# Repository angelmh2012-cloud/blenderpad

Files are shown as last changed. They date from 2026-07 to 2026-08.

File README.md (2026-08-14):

# BlenderPad

BlenderPad is a custom macropad project built for Blender workflow shortcuts, gaming controls, and a small OLED mini game. It is designed to be programmable with CircuitPython and KMK firmware, making it easy to customize for different use cases.



## Project Overview
This project started as a beginner-friendly hardware and firmware build for HackClub. The goal is to create a compact keypad that can:
- trigger Blender shortcuts quickly
- switch between different key modes
- show the active mode on an OLED display
- support simple gaming-style input mappings

## What is included
This repository contains:
- a beginner-friendly 3D-printable case concept
- PCB design files
- firmware for the microcontroller
- a custom main script for mode switching and OLED output

## Hardware Features
The current design uses:
- an encoder for changing modes
- an OLED display for showing the active mode
- keys connected to GPIO pins for custom actions
- support for multiple functional profiles
  



## Firmware Details
The firmware is written in Python and uses KMK for keyboard behavior. The device supports:
- Blender shortcuts mode
- Friday Night Funkin mode
- a mini game mode displayed on the OLED screen

## Pin Layout
- SDA: D4
- SCL: D5
- Encoder: D1
- Keys: D7 to D10

## Software Requirements
The firmware relies on the following Python libraries:
- adafruit-circuitpython-ssd1306
- adafruit-circuitpython-busdevice
- adafruit-circuitpython-framebuf

## How to Use It
1. Flash CircuitPython onto the microcontroller.
2. Copy the firmware files and required libraries to the device.
3. Upload the main script.
4. Power the board and test the keys and encoder.

## Notes
This is a beginner project, so the design and firmware are still evolving. The main goal is to learn hardware programming, PCB design, and embedded firmware development in a fun and practical way.

## Future Ideas
Possible improvements include:
- adding more Blender shortcuts
- creating custom profiles for different programs
- improving the OLED mini game
- refining the case design for a cleaner final build

## Summary
BlenderPad is a fun, hands-on project that combines electronics, firmware, and creativity into one compact macropad. It is a great example of how small embedded projects can become useful tools for everyday tasks.

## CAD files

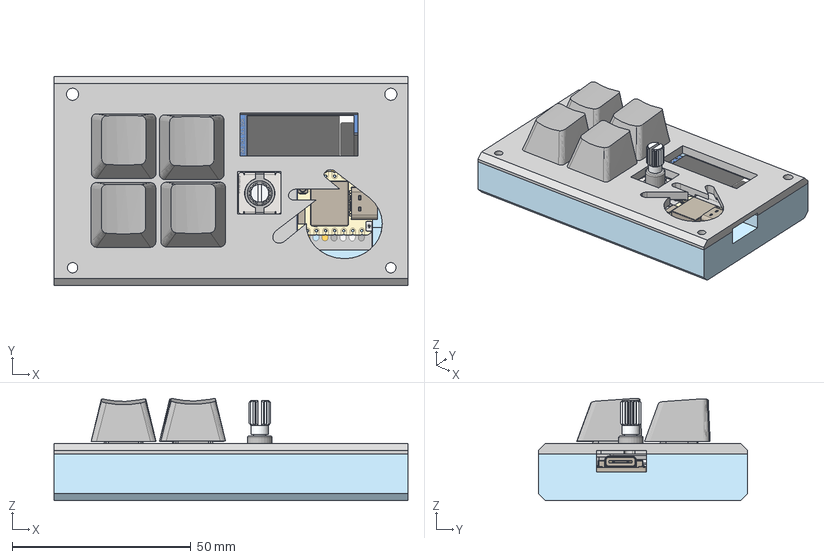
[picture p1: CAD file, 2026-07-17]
CAD/BlenderPad v1.step
99.0 x 58.5 x 28.6 mm
Surface 43
Surface 364
Surface 344
Surface 180
Surface 40
Surface 131
Surface 284
Surface 30
Surface 79
Surface 341
Surface 146
Surface 207
Surface 29
Surface 252
Surface 245
Surface 107
Surface 33
Surface 233
Surface 373
Surface 37
Surface 99
Surface 230
Surface 282
Surface 194
Surface 178
Surface 261
Surface 383
Surface 309
Surface 257
Surface 155
Surface 397
Surface 321
Surface 44
Surface 185
Surface 162
Surface 269
Surface 313
Surface 141
Surface 57
Surface 154
Surface 12
Surface 324
Surface 115
Surface 147
Surface 291
Surface 231
Surface 243
Surface 256
Surface 320
Surface 312
Surface 145
Surface 116
Surface 235
Surface 381
Seeed Studio XIAO-ESP32-C6
Surface 21
Surface 6
Surface 259
Surface 159
Surface 77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

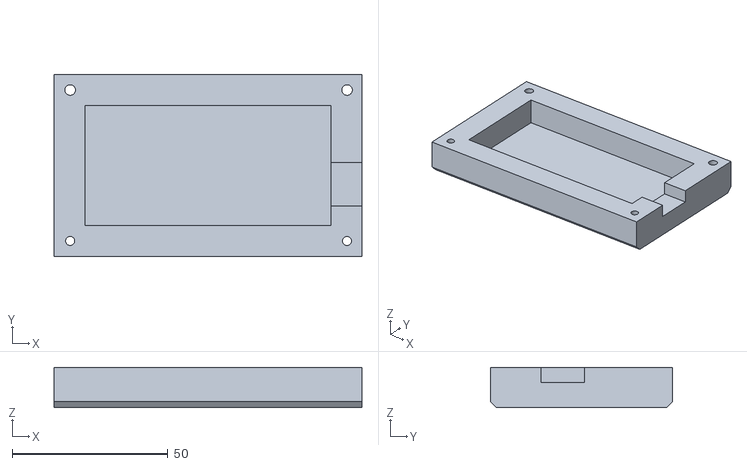
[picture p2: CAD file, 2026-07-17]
Production/Bottom(1).stl
99.0 x 58.5 x 13.0

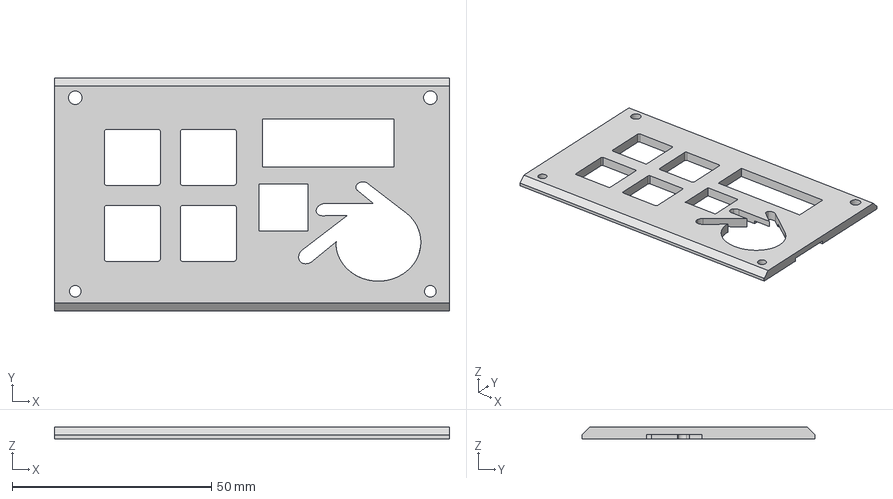
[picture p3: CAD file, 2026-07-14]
CAD/Top.step
99.0 x 58.5 x 3.00 mm

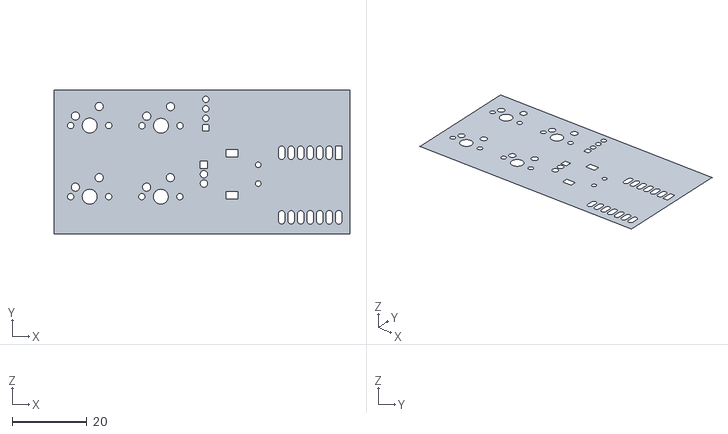
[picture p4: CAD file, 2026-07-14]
CAD/PCB surface.stl
79.0 x 38.5 x 0

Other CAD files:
Production/Top(1).stl
CAD/Bottom.step

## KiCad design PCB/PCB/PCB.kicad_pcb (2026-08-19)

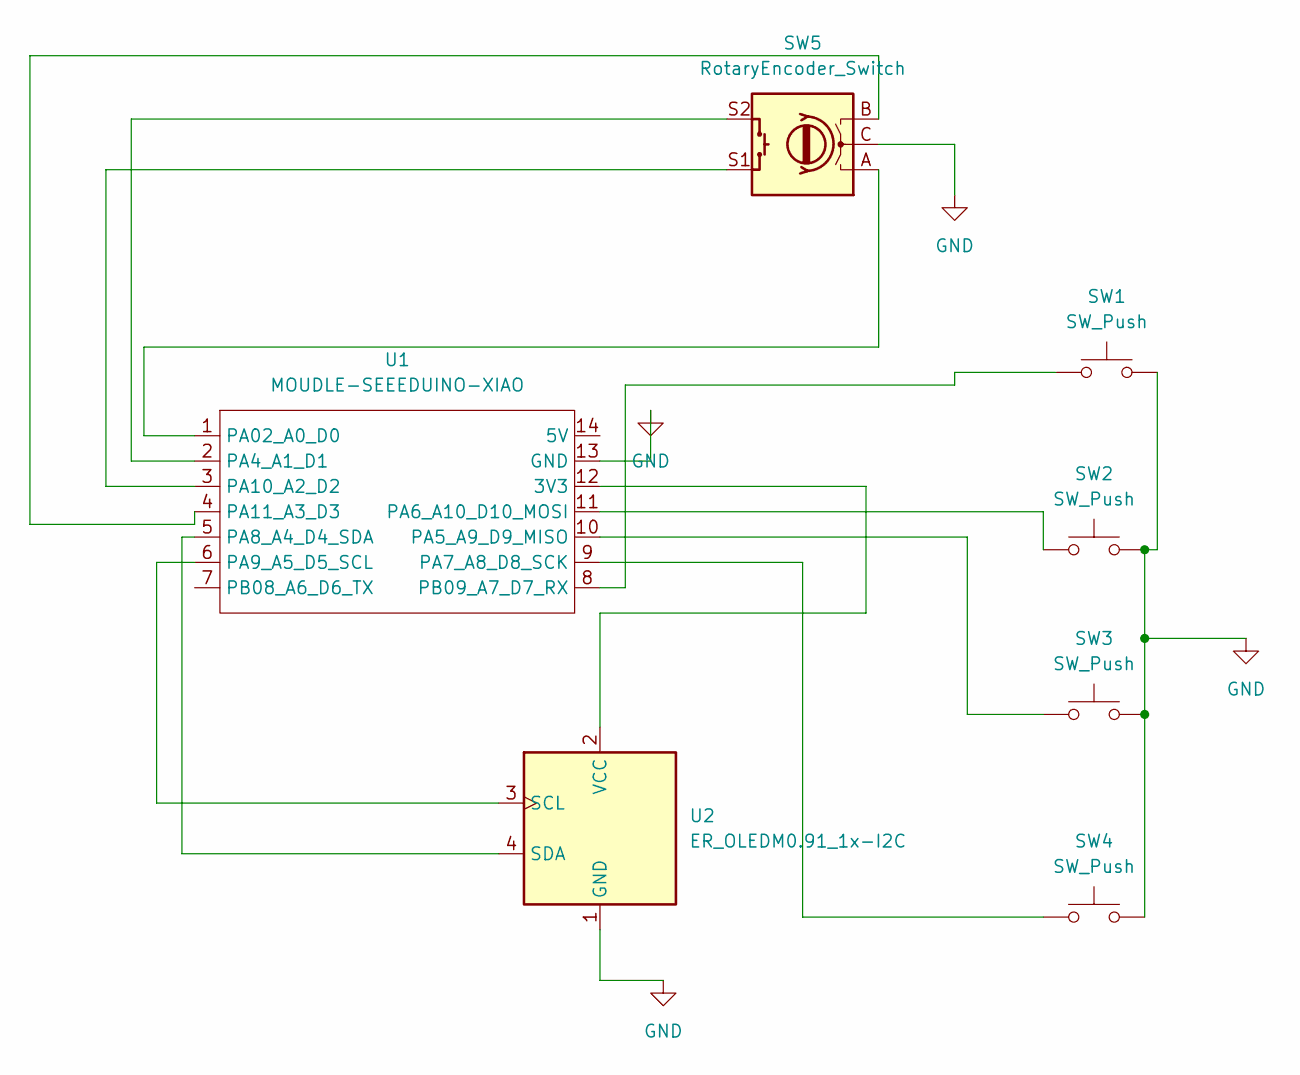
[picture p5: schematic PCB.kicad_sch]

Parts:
SW1, SW2, SW3, SW4: SW_Push; SW_Cherry_MX_1.00u_PCB
SW5: RotaryEncoder_Switch; RotaryEncoder_Alps_EC11E-Switch_Vertical_H20mm
U1: MOUDLE-SEEEDUINO-XIAO; XIAO-Generic-Hybrid-14P-2.54-21X17.8MM
U2: ER_OLEDM0.91_1x-I2C

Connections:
GND: SW1.2, SW2.2, SW3.2, SW4.2, SW5.C, U1.13 (GND), U2.1 (GND)
unnamed: U1.12 (3V3), U2.2 (VCC)
unnamed: SW5.A, U1.1 (PA02_A0_D0)
unnamed: SW5.S2, U1.2 (PA4_A1_D1)
unnamed: SW3.1, U1.10 (PA5_A9_D9_MISO)
unnamed: SW2.1, U1.11 (PA6_A10_D10_MOSI)
unnamed: SW4.1, U1.9 (PA7_A8_D8_SCK)
unnamed: U1.5 (PA8_A4_D4_SDA), U2.4 (SDA)
unnamed: U1.6 (PA9_A5_D5_SCL), U2.3 (SCL)
unnamed: SW5.S1, U1.3 (PA10_A2_D2)
unnamed: SW5.B, U1.4 (PA11_A3_D3)
unnamed: SW1.1, U1.8 (PB09_A7_D7_RX)

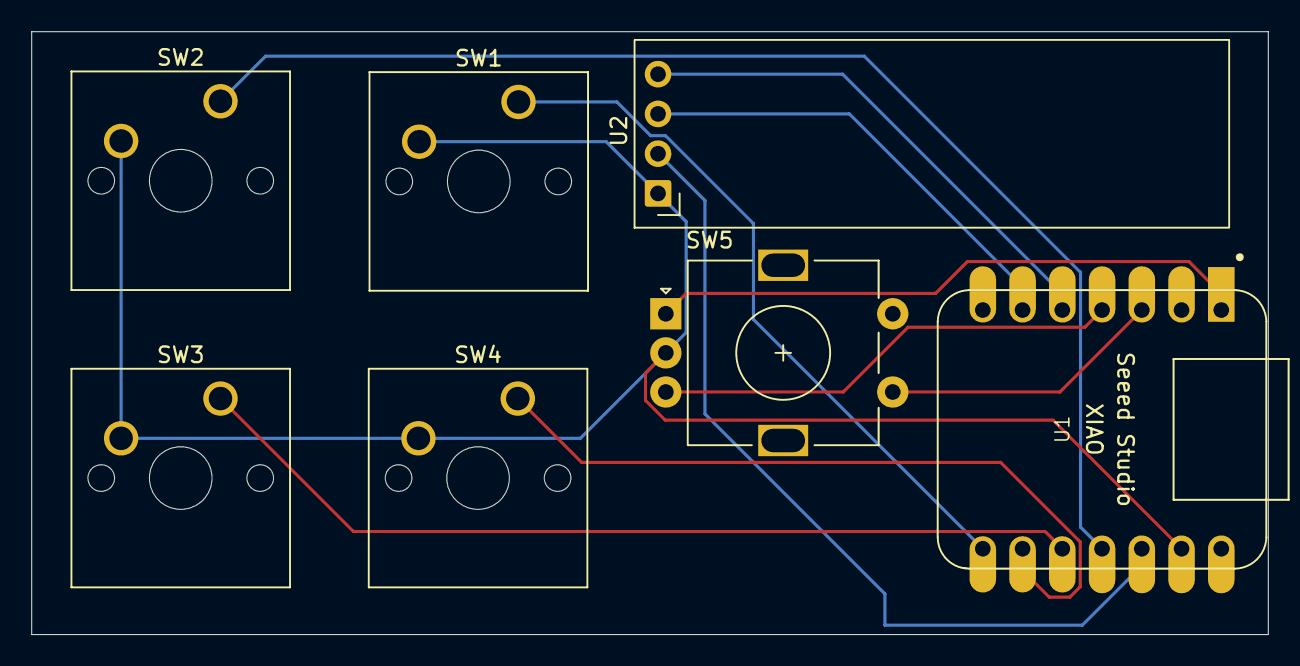
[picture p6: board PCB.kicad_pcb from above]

Board: 2 copper layers, 79.0 x 38.5 mm, 7 parts (0 on the bottom side), 12 nets.

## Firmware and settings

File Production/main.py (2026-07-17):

import time

import board
from kmk.kmk_keyboard import KMKKeyboard
from kmk.keys import KC
from kmk.modules.holdtap import HoldTap
from kmk.modules.macros import Macro

try:
    import digitalio
except ImportError:  # pragma: no cover - handles host-side syntax checks
    digitalio = None

try:
    import adafruit_ssd1306
except ImportError:  # pragma: no cover - handles host-side syntax checks
    adafruit_ssd1306 = None

from kmk.scanners.diode import DiodeOrientation

modtap = HoldTap()
macros = Macro()
keyboard = KMKKeyboard()

keyboard.modules.append(modtap)
keyboard.modules.append(macros)

# --- Key layout: 2x2 matrix mapped to D7-D10 ---
keyboard.col_pins = ()
keyboard.row_pins = ()
keyboard.diode_orientation = DiodeOrientation.COL2ROW

ENFOCAR_OBJ = KC.F
DUPLICAR_OBJ = KC.H
MOSTRAR_TODO = KC.LALT(KC.H)
ABRIR_PROP = KC.N

MODES = ["Blender Shortcuts", "Friday Night Funkin", "Mini Game"]
MODE_HINTS = [
    "F=focus | H=hide | Alt+H=show all",
    "Arrows for notes | A/S/W/D as extras",
    "OLED mini game + button actions",
]
MODE_ACTIONS = [
    [ENFOCAR_OBJ, DUPLICAR_OBJ, MOSTRAR_TODO, ABRIR_PROP],
    [KC.LEFT, KC.DOWN, KC.UP, KC.RIGHT],
    [KC.A, KC.S, KC.W, KC.D],
]

current_mode = 0


def get_pin(*names):
    for name in names:
        pin = getattr(board, name, None)
        if pin is not None:
            return pin
    raise RuntimeError("Could not find a matching pin for the requested hardware")


# --- Hardware pins ---
SDA_PIN = get_pin("GP4", "D4")
SCL_PIN = get_pin("GP5", "D5")
ENCODER_PIN = get_pin("GP1", "D1")
BUTTON_PINS = [get_pin("GP7", "D7"), get_pin("GP8", "D8"), get_pin("GP9", "D9"), get_pin("GP10", "D10")]


# --- OLED setup ---
if digitalio is not None and adafruit_ssd1306 is not None:
    import busio

    i2c = busio.I2C(SCL_PIN, SDA_PIN)
    oled = adafruit_ssd1306.SSD1306_I2C(128, 32, i2c, addr=0x3C)
else:
    oled = None


# --- Button inputs ---
if digitalio is not None:
    buttons = []
    for pin in BUTTON_PINS:
        io = digitalio.DigitalInOut(pin)
        io.direction = digitalio.Direction.INPUT
        io.pull = digitalio.Pull.UP
        buttons.append(io)

    encoder_button = digitalio.DigitalInOut(ENCODER_PIN)
    encoder_button.direction = digitalio.Direction.INPUT
    encoder_button.pull = digitalio.Pull.UP
else:
    buttons = []
    encoder_button = None

button_last_states = [False] * len(buttons)
encoder_last_state = False


def draw_status():
    if oled is None:
        return

    oled.fill(0)
    oled.text("Mode:", 0, 0, 1)
    oled.text(MODES[current_mode][:12], 0, 10, 1)
    oled.text(MODE_HINTS[current_mode][:16], 0, 20, 1)
    oled.show()


# --- Simple OLED mini game ---
ball_x = 10
ball_y = 10
ball_dx = 2
ball_dy = 1


def draw_game_frame():
    global ball_x, ball_y, ball_dx, ball_dy

    if oled is None:
        return

    oled.fill(0)
    oled.text("Mini Game", 0, 0, 1)
    oled.pixel(ball_x, ball_y, 1)
    oled.pixel(ball_x + 1, ball_y, 1)
    oled.pixel(ball_x, ball_y + 1, 1)
    oled.pixel(ball_x + 1, ball_y + 1, 1)

    ball_x += ball_dx
    ball_y += ball_dy

    if ball_x <= 0 or ball_x >= 126:
        ball_dx *= -1
    if ball_y <= 8 or ball_y >= 30:
        ball_dy *= -1

    oled.show()


# --- Helper to send key presses ---
def send_key(action):
    try:
        keyboard.tap_key(action)
    except AttributeError:
        pass


# --- Background task for encoder/button handling and OLED output ---
def control_loop():
    global current_mode, button_last_states, encoder_last_state

    while True:
        if buttons:
            for idx, button in enumerate(buttons):
                pressed = not button.value
                if pressed and not button_last_states[idx]:
                    action = MODE_ACTIONS[current_mode][idx]
                    send_key(action)
                button_last_states[idx] = pressed

        if encoder_button is not None:
            pressed = not encoder_button.value
            if pressed and not encoder_last_state:
                current_mode = (current_mode + 1) % len(MODES)
                draw_status()
            encoder_last_state = pressed

        if current_mode == 2:
            draw_game_frame()
        else:
            draw_status()

        time.sleep(0.05)


keyboard.keymap = [[KC.NO, KC.NO], [KC.NO, KC.NO]]

if __name__ == '__main__':
    draw_status()
    try:
        import _thread
    except ImportError:  # pragma: no cover - handles host-side syntax checks
        _thread = None

    if _thread is not None:
        _thread.start_new_thread(control_loop, ())

    keyboard.go()

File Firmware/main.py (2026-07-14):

from kmk.handlers.sequences import simple_key_sequence, send_string
import board
from kmk.kmk_keyboard import KMKKeyboard
from kmk.keys import KC
from kmk.modules.holdtap import HoldTap
from kmk.modules.macros import Press, Release, Tap, Delay, Macro

modtap = HoldTap()
macros = Macro()

keyboard = KMKKeyboard()

# Configuración genérica de pines (Ajústalos a los pines reales de tu placa)
# En este ejemplo usamos una matriz de 2x2 para las 4 teclas
keyboard.col_pins = (board.GP0)
keyboard.row_pins = (board.GP1, board.GP2, board.GP3)
keyboard.diode_orientation = col2row
keyboard.modules.append(modtap)
keyboard.modules.append(macros)


ENFOCAR_OBJ  = KC.PDOT      # Hace zoom/focus al objeto seleccionado
DUPLICAR_OBJ  = KC.H         # Oculta el objeto seleccionado
MOSTRAR_TODO = KC.LALT(KC.H) # Revela todo lo oculto (Alt + H)


OPEN_BLENDER = [
     KC.LWIN(no_release=True),
        KC.R,
        KC.LWIN(no_press=True),
        KC.MACRO_SLEEP_MS(250), # Wait for the Run window to pop up
        send_string("Blender.exe"),
        KC.ENTER,
]
VISTA_Z = KC.Z,        

TECLA_DOBLE = KC.HT(VISTA_Z, OPEN_BLENDER, prefer_hold=True, tap_time=250)

keyboard.keymap = [
    [
        # Fila 1: Botón Izquierdo, Botón Derecho
        TECLA_DOBLE,           ENFOCAR_OBJ,
        
        # Fila 2: Botón Izquierdo, Botón Derecho
        DUPLICAR_OBJ,       MOSTRAR_TODO
    ]
]

if __name__ == '__main__':
    keyboard.go()

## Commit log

2026-07-16 Add a .STEP file for all the project
    [BlenderPad v1.step]
2026-07-17 Add main functionality for keyboard control and OLED display
    - Implemented a 2x2 matrix keyboard layout with key mappings for different modes.
    - Integrated OLED display to show current mode and hints.
    - Added a simple mini game with ball movement on the OLED.
    - Set up button inputs and encoder handling for mode switching and key actions.
    - Established a control loop for continuous input handling and display updates.
    [Bottom(1).stl, Top(1).stl]
2026-08-11 Update PCB adding resistors
    [PCB.kicad_pcb, PCB.kicad_sch]
2026-08-11 add new gerbers for updated pcb
